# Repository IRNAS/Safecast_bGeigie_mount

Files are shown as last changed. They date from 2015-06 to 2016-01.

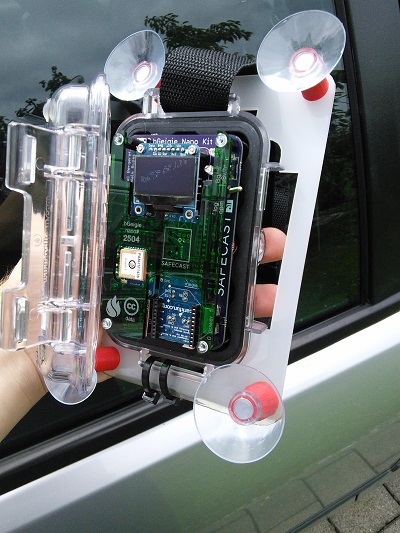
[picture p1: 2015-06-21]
bGeigie_mount1.jpg

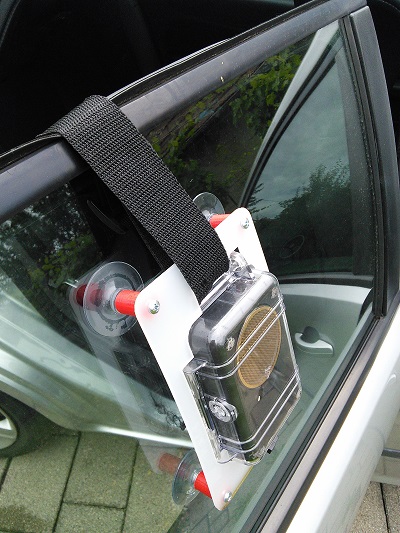
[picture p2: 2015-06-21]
bGeigie_mount3.jpg

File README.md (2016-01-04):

# Safecast bGeigie nano mount

This simple suction cup mounting attachment is designed to keep a [Safecast](http://blog.safecast.org/) [bGeigie nano](http://blog.safecast.org/) Geiger counter logger securely mounted on the car while driving at higher speeds. If simply hung out of the window, the unit starts flapping, but suction cups keep it secure.

Mounting plate can be easily cut from wood or plastic with a laser or milled with a CNC router. Commonly available suction cups with M4 threads (check ebay, amazon) can be attached with some 3D printed spacers to the plate. Size of the spacers matters if you wish to mount the unit on the inside of the car window or the outside. Spacers in the STL files are designed for 6mm mounting plate thickness, you can adjust this parameter in OpenSCAD and generate spacers as needed.

Attach the bottom of the bGeigie with two zip-ties to the mounting plate and run the strap through the top of the bGeigie and loop it around the door with the car window opened. Now you can tilt the bGeigie from the plate to open it and turn it on. Then close it and press the suction cups to glass, close the window and tighten the strap. Your bGeigie is securely mounted now and you can safely drive at higher speeds. Note that some buzzing noise may occur due to air passing across the setup.

bGeigie mount
bGeigie mount
bGeigie mount

---

#### License

All our projects are as usefully open-source as possible.

Hardware including documentation is licensed under [CERN OHL v.1.2. license](http://www.ohwr.org/licenses/cern-ohl/v1.2)

Firmware and software originating from the project is licensed under [GNU GENERAL PUBLIC LICENSE v3](http://www.gnu.org/licenses/gpl-3.0.en.html).

Open data generated by our projects is licensed under [CC0](https://creativecommons.org/publicdomain/zero/1.0/legalcode).

All our websites and additional documentation are licensed under [Creative Commons Attribution-ShareAlike 4 .0 Unported License] (https://creativecommons.org/licenses/by-sa/4.0/legalcode).

What this means is that you can use hardware, firmware, software and documentation without paying a royalty and knowing that you'll be able to use your version forever. You are also free to make changes but if you share these changes then you have to do so on the same conditions that you enjoy.

Koruza, GoodEnoughCNC and IRNAS are all names and marks of Institut IRNAS Rače. 
You may use these names and terms only to attribute the appropriate entity as required by the Open Licences referred to above. You may not use them in any other way and in particular you may not use them to imply endorsement or authorization of any hardware that you design, make or sell.

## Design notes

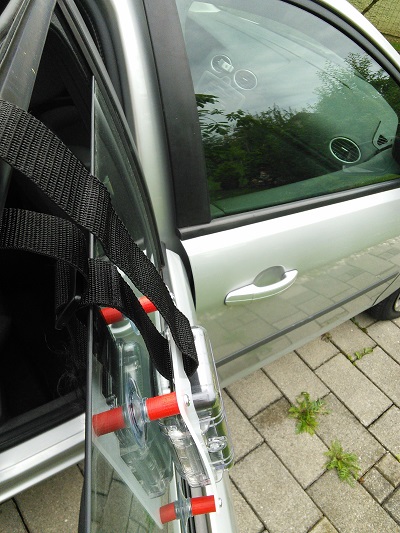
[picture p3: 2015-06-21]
bGeigie_mount2.jpg

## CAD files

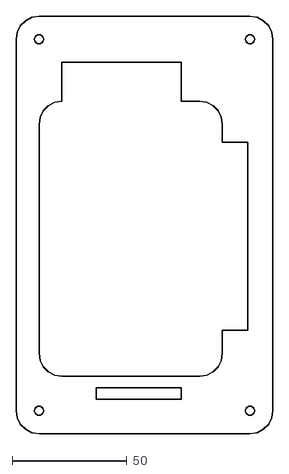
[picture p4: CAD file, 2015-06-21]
Safecast_bGeigieMount.dxf
112.0 x 182.0

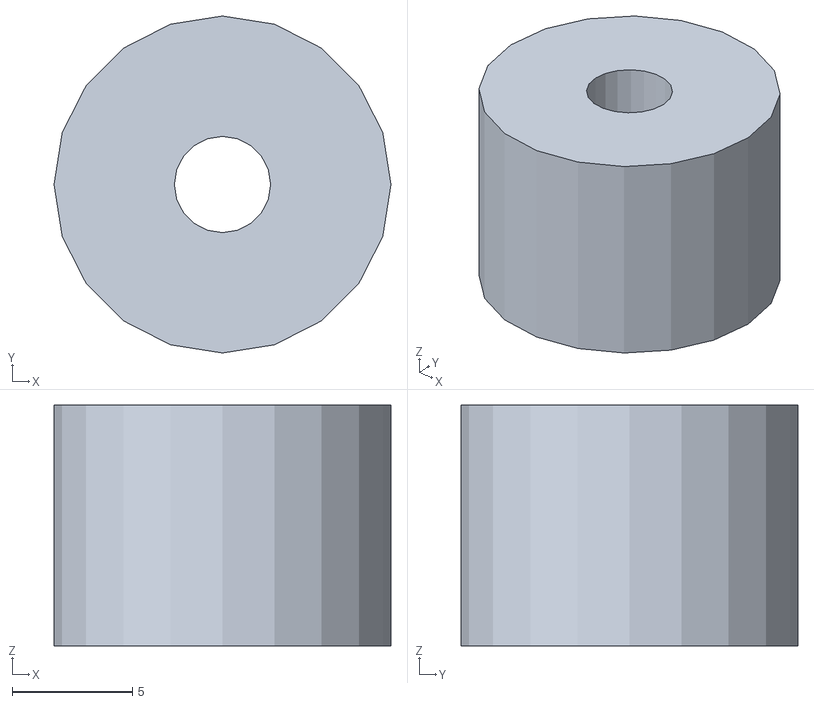
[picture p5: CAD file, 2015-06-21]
Safecast_bGeigieMount_spacer_in.stl
14.0 x 14.0 x 10.0

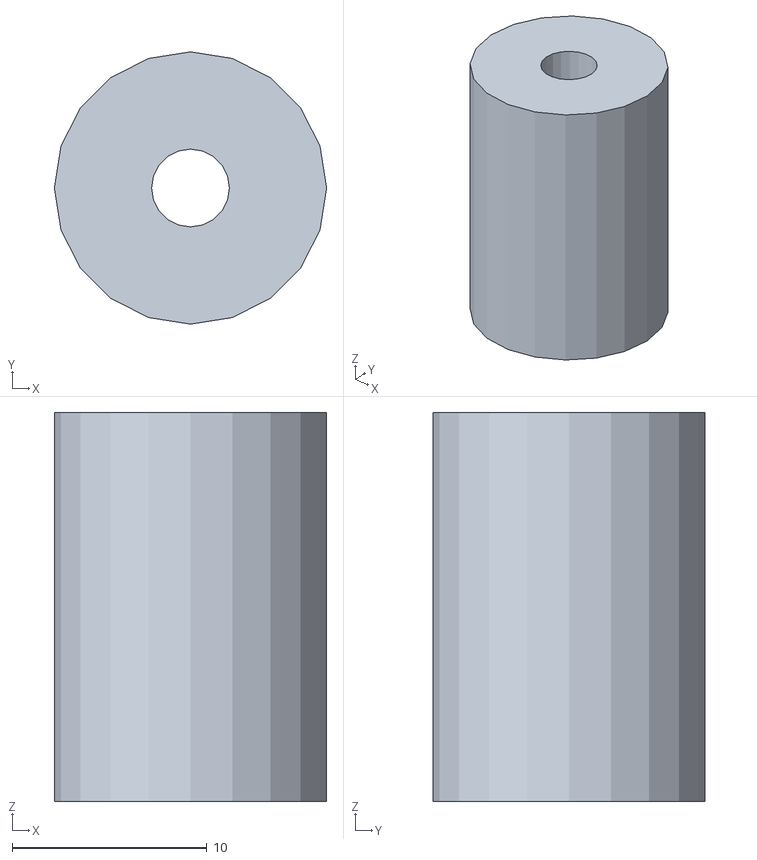
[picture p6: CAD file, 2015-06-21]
Safecast_bGeigieMount_spacer_out.stl
14.0 x 14.0 x 20.0

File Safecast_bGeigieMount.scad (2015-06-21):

/* Car window suction cup mount for Safecast bGeigie so it stops flapping at high speeds

Copyright Institute IRNAS Rače 2015. 

This documentation describes Open Hardware and is licensed under the CERN OHL v. 1.2.
You may redistribute and modify this documentation under the terms of the [CERN OHL v.1.2.](http://ohwr.org/cernohl). This documentation is distributed WITHOUT ANY EXPRESS OR IMPLIED  WARRANTY, INCLUDING OF MERCHANTABILITY, SATISFACTORY QUALITY AND FITNESS FOR A PARTICULAR PURPOSE. Please see the CERN  OHL  v.1.2 for applicable conditions.*/

//Define the following variables as per your use-case

//Material thickness of the lasercut plate affects spacer dimensions
thickness=6;

//spacer if safecast is mounted on the outside surface (screen towards glass)
module spacer_out(){
	//7mm thickness of suction cup
	height=33-7-thickness;
	difference(){
		//spacer itself
		cylinder(h=height,r=7,$fn=20,center=true);
		//4mm hole for screw
		cylinder(h=height,r=2,$fn=20,center=true);
	}
}

//spacer if safecast is mounted on the inside surface (sensor towards glass))
module spacer_in(){
	//7mm thickness of suction cup
	height=23-7-thickness;
	difference(){
		//spacer itself
		cylinder(h=height,r=7,$fn=20,center=true);
		//4mm hole for screw
		cylinder(h=height,r=2,$fn=20,center=true);
	}
}

//cutout for the case
module coutout(){
	hull() {
		for(x=[10,70]){
			for(y=[10,110]){
				rotate([0,0,0])
				translate([x,y,0])
				cylinder(h=5,r=10,$fn=20,center=true);
			}
		}	
	}
	//opening for close mechanism
	translate([82+3,122/2,0]) cube([12,82,5],center=true);
	//bottom strap cut
	translate([82/2+2.5,-7.5,0])	cube([37,5,5],center=true);
	//top strap cut
	translate([82/2-5,128,0])	cube([52,18,5],center=true);
}

//hole for the suction cup or spacer
module cup_hole(){
	//4mm hole for screw
	cylinder(h=5,r=2,$fn=20,center=true);
}

//cup/spacer position
module cup(){
	//cups in corner
	translate([0,-15,0]) cup_hole();
	translate([92,-15,0]) cup_hole();
	translate([92,147,0]) cup_hole();
	translate([0,147,0]) cup_hole();
}

//plate definition
module main(){
	hull() {
		for(x=[0,92]){
			for(y=[-15,147]){
				rotate([0,0,0])
				translate([x,y,0])
				cylinder(h=5,r=10,$fn=20,center=true);
			}
		}	
	}
}

//making all the holes
module final(){
	difference(){
		main();
		coutout();
		cup();
	}
}

//creating the STL object for plate
//final();
//or creating the DXF
projection(cut = true) final();

//creating the STL object for outer spacer
//spacer_out();

//creating the STL object for inner spacer
//spacer_in();
